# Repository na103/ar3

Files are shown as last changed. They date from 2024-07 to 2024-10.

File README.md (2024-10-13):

# Amiga Action Replay III remake

This repository contains the reverse engineering schematic for the Amiga Action Replay III and everything needed to build it.<br>
<br>
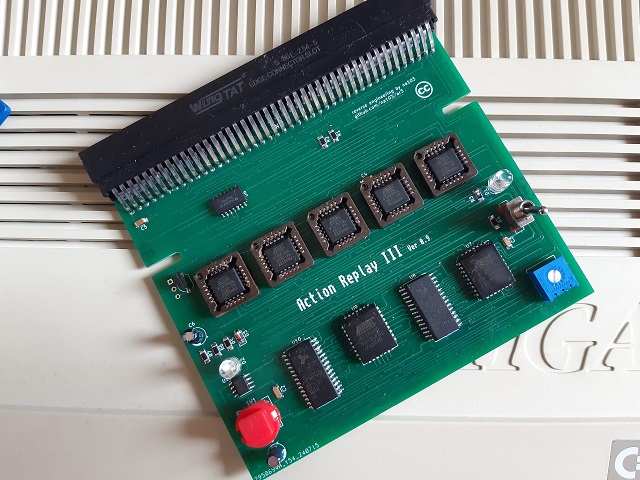
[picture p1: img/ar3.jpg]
AR3

<br>
<br>

## Bill of materials
| Qt. | Description | Designator | Mouser part | Note |
|:---:|---|---|---|---|
|6 |Resistor 1K |R1-R4, R6, R7 |CRCW12061K00FKEA | |
|1 |Resistor 4.7K |R5 |CRCW12064K70FKEA | |
|1 |Cap. 10uF 16V |C1 |EEA-FC1E100H | |
|4 |Cap. 100nf |C2-C5 |C1206C104K5RAC7867  | |
|1 |Cap. 1uF 63V |C6 |ESS105M050AB2AA | |
|5 |GAL16V8 |U1-U5 |ATF16V8BQL-15JU | | 
|5 |PLCC 20 POS Socket  |U1-U5 |540-88-020-17-400-TR| Optional |
|2 |DIP 32P Socket |U7, U9 |4832-6000-CP | Optional in EPROM version |
|1 |74F74 |U6 |SN74LS74ANSR | |
|2 |27C010 OTP EPROM |U7, U9 |AT27C010-70JU-T | PLCC 32 OTP EPROM version |
|2 |M27C1001 EPROM |U7, U9 |M27C1001-10F1 | DIP 32 EPROM version |
|1 |SRAM 64K |U8 |AS6C6264-55SCN | |
|1 |SRAM 256K |U10 |AS6C62256-55SCN | |
|1 |MC1455 |U11 |MC1455DR2G | |
|1 |ZVP2106A |Q1 |ZVP2106A | |
|1 |Trimmer 10K |VR1 |3362F-1-103LF | |
|1 |Red LED |D1 |TLCS5100 | |
|1 |Green LED |D2 |TLCYG5100 | |
|1 |Diode |D3 |LL4148-M-18 | |
|1 |Button switch red |SW1 |D6C40F1LFS | |
|1 |SPDT ON-ON switch |SW2 |2MS1T1B3M2QES | |
|1 |Conn edge female 86p|CN1 |ECC43DCAI-S189 | from ebay or digikey ECC43DCAI-S189 |

<br><br>
Now thanks to fongo2k is now available the 3D printed case for the AR3 replica.<br>
[https://www.printables.com/model/1037033-amiga-action-replay-3-replica-case](https://www.printables.com/model/1037033-amiga-action-replay-3-replica-case)
<br><br>
If you found this my work useful, please consider buying me a cup of coffee if you want:<br>


# License

This work is licensed under a Creative Commons Attribution 4.0 International License. See [https://creativecommons.org/licenses/by/4.0/](https://creativecommons.org/licenses/by/4.0/).

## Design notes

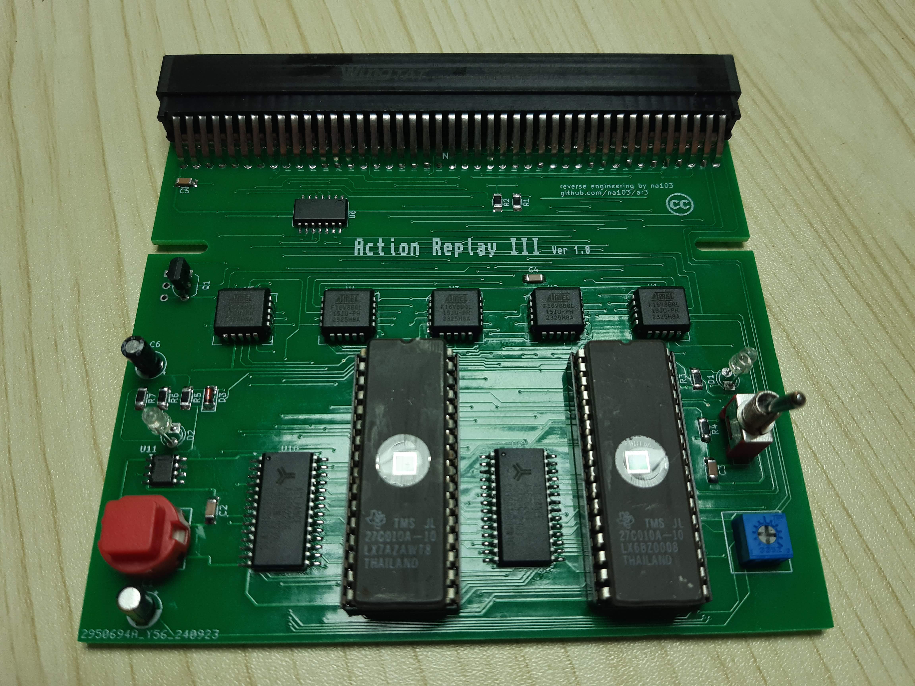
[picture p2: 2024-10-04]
img/eprom_version.jpg

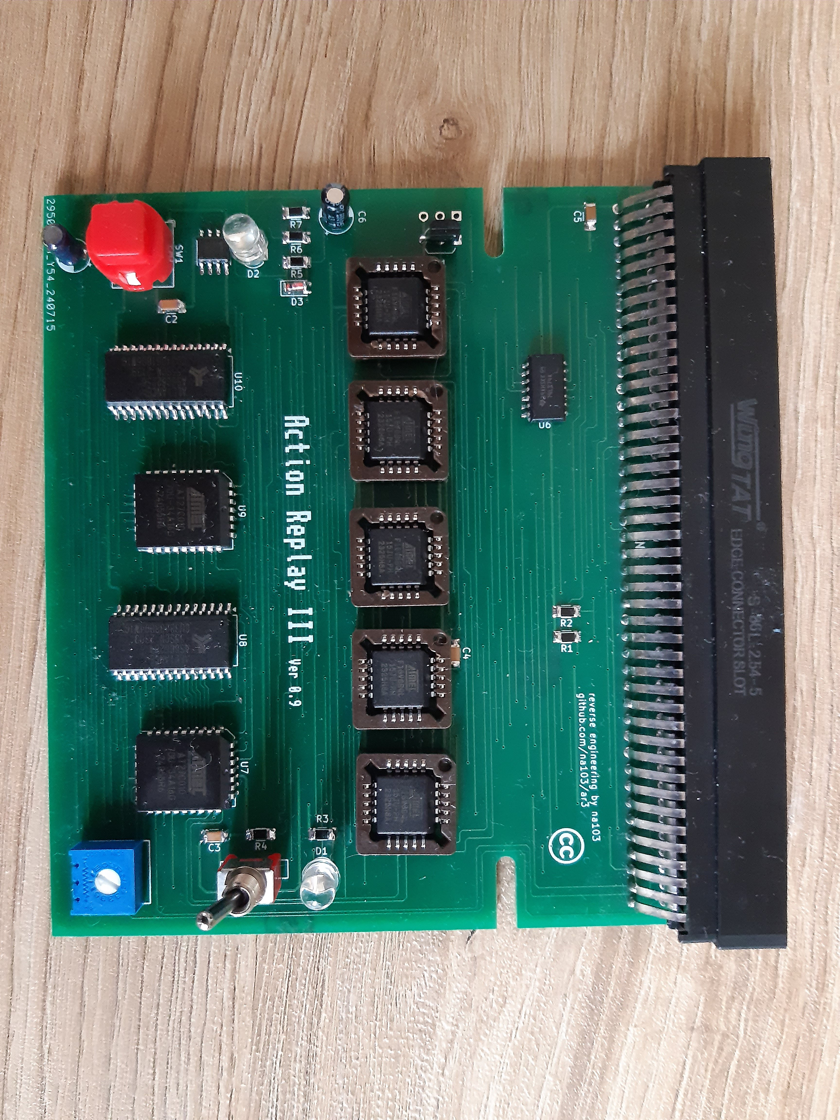
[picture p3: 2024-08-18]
img/front.jpg

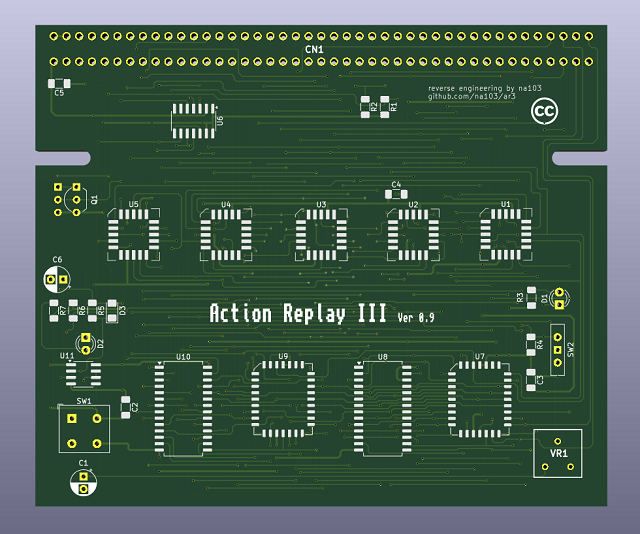
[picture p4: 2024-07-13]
img/3d_1.png

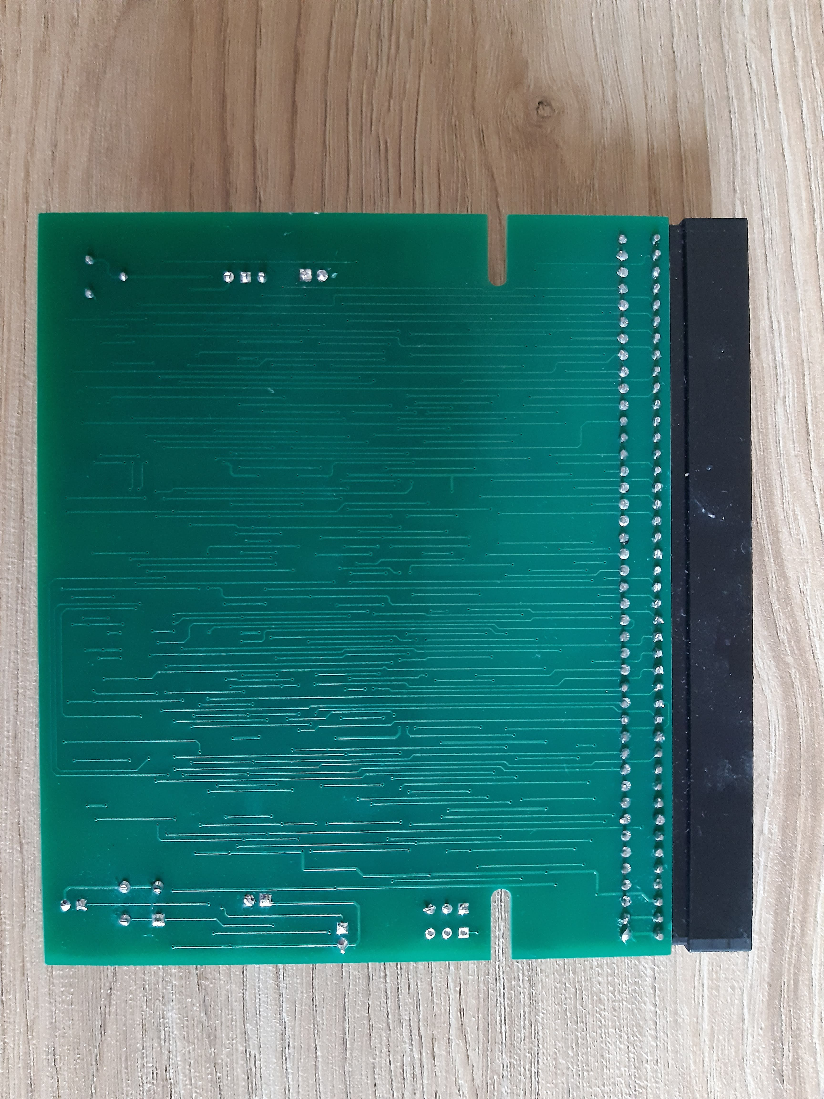
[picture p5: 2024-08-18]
img/rear.jpg

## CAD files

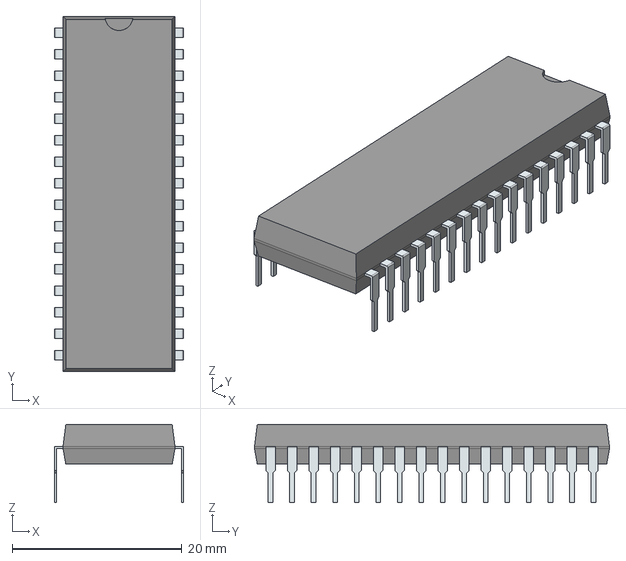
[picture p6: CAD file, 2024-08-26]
Kicad/ARIII_EPROM/M27C1001-12F1/M27C1001-12F1.stp
15.3 x 41.9 x 9.22 mm
PinsArrayLR

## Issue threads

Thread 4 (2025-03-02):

Action Replay MK III foil repro

reinauer, 2025-03-02:
I played a bit with Inkscape and made this:

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

na103, 2025-03-03:
i like it, it looks perfect. i will try to print it to see if it fits the ar3 replica.
what do you think about making a similar one for DeMoN?
https://github.com/gerbilbyte/DeMoN
I can send you the DeMoN logo and the 3d print project of the modified case.

Closed 2025-03-03.

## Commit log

2024-07-12 Kicad project
    [ARIII-B_Cu.gbr, ARIII-B_Mask.gbr, ARIII-B_Paste.gbr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]
2024-07-13 routing reworking
    [ARIII-B_Cu.gbr, ARIII-B_Mask.gbr, ARIII-B_Paste.gbr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]
2024-07-14 routing adjustment
    [ARIII-B_Cu.gbr, ARIII-B_Mask.gbr, ARIII-B_Paste.gbr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]
2024-08-18 Pcb rev 1.0
    [ARIII-B_Cu.gbr, ARIII-B_Mask.gbr, ARIII-B_Paste.gbr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]
2024-08-26 27C1001 EPROM version
    [ARIII_EPROM-B_Cu.gbr, ARIII_EPROM-B_Mask.gbr, ARIII_EPROM-B_Paste.gbr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]
2024-09-14 Added .gitignore file for Kicad project and removed files that should have been ignored
2024-09-14 Replaced footprints for U8 and U10
    [ARIII_EPROM.kicad_sch]
2024-09-14 Replaced EPROM footprints with custom footprints from a project library
    [ARIII_EPROM.kicad_sch]
2024-09-14 Replaced 74LS74 footpint with a custom footprint that both supports 3.9mm and 5.3mm parts
2024-09-15 Changed footprint association for U6
    [ARIII_EPROM.kicad_sch]
2024-09-16 update gerber file
    [ARIII_EPROM-B_Cu.gbr, ARIII_EPROM-B_Mask.gbr, ARIII_EPROM-B_Paste.gbr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]
2024-09-16 Replaced footprints for U8 and U10 with one that better fits the ICs
    [ARIII.kicad_sch]
2024-09-18 Gerber update
    [ARIII-B_Cu.gbr, ARIII-B_Mask.gbr, ARIII-B_Paste.gbr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]
2024-10-04 fixed cn1 pin numbering
    [ARIII-B_Cu.gbr, ARIII-B_Mask.gbr, ARIII-B_Paste.gbr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]
